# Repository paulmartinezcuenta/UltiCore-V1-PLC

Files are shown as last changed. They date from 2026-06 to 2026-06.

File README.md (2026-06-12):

# UltiCore V1 - ESP32-Based Industrial PLC 

UltiCore V1 is a high-reliability, industrial-grade Programmable Logic Controller (PLC) custom-designed around the **ESP32-WROOM-32D** architecture. Engineered for harsh electrical environments, this board features high-density optical isolation, dedicated buffered data buses, and a robust power management system.

---

##  Advanced Hardware Architecture & Engineering

### 1. Dual-Bus Data Architecture & Control Logic
* **Buffered Bus Isolation:** Implements octal three-state buffers (**74HC541TS**) to split control signals into dedicated **Power Data Buses** and **Analog Data Buses**. This topology isolates the MCU pins, maximizes fan-out capability, and prevents EMI crosstalk from high-current switching sections.
* **Industrial Output Stage (8-Channel Relay Matrix):** Features 8 independent mechanical relays driven by robust **2N3904** BJT switching circuits. Each channel is equipped with hardwired pull-down networks for deterministic power-up states and **RR1VWM6STFTR** flyback suppression diodes to clamp inductive back-EMF spikes.

### 2. High-Density Input Conditioning & Galvanic Isolation
* **Optically Isolated Digital Inputs:** 8 industrial-level input channels (`IN0`-`IN7`) isolated via high-density **ILD207T** dual optocouplers, establishing complete galvanic separation between the 24V field domain and the 3.3V logic domain.
* **Hardware Debouncing & Waveshaping:** Optocoupler outputs are routed through **74HC14** Hex Schmitt-Trigger inverters to suppress mechanical switch bounce and electrical noise, delivering sharp, clean square waves to the MCU.

### 3. Industrial Power Supply & Protection Framework
* **High-Efficiency Buck Topology:** Integrates an **LM2576HVS-3.3** switching regulator paired with a **100µH** power inductor and a **B330A** Schottky diode to efficiently step down standard industrial 24VDC rails directly to a stable 3.3V rail.
* **Smart Dual-Power Protection (Anti-USB & 24V Cross-Protection):** Utilizes an **LM358DR** operational amplifier comparator circuit coupled with a **PC817** optocoupler and an **FQD11P06** P-Channel MOSFET. This layout actively prevents reverse-current backfeeding and hardware damage when both the high-voltage field power and USB-C programming interface are active simultaneously.
* **Front-End Overcurrent & Polarity Defense:** Equipped with a standard 5x20mm cartridge fuse assembly and a high-current **5S14** blocking diode for reverse-polarity protection.

### 4. Modern Interface & ESD Compliance
* **USB-C Interface:** Modern USB-C implementation driven by a **CH340C** USB-to-UART bridge with an integrated dual-transistor auto-reset/boot-loader circuit.
* **Transient Voltage Suppression:** High-speed **LESD5D5.0CT1G** TVS diode arrays deployed on critical USB data lines (`D+`/`D-`) for localized ESD clamping.

---

## Repository Structure

```text
├── Hardware/        # KiCad schematic captures, multi-layer layout files, and structural BOM
├── Firmware/        # Modular C/C++ source code and RTOS industrial automation tasks
└── Docs/            # Hardware layout sheets, pinout mapping, and component datasheets

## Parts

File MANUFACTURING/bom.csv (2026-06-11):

Designator | Footprint | Quantity | Value | LCSC Part #
C1, C4, C6 | 0805 | 3 | 10uf_25v
C10 | C_Elec_10x10.2 | 1 | 470uf | C72518
C11 | C_Elec_6.3x7.7 | 1 | 47uf | C72523
C12 | C_Elec_8x10.2 | 1 | 220uf
C13, C14, C15, C16, C17, C18, C19, C20, C21, C22, C23, C24, C25, C26, C27, C28, C29, C30, C31, C32, C37, C38, C40, C41, C42, C43, C5, C9 | 0805 | 28 | 100nf
C2, C3 | 0805 | 2 | 0.1uf_50v
C34, C35, C36 | 0805 | 3 | 10uf
C7, C8 | 0805 | 2 | 0.1uf
CN1, CN3 | CONN-TH_2P-P5.08_DIBO_DB128V-5.08 | 2 | DB128V-5.08-2P-GN-S | C2915639
CN2 | CONN-TH_8P-P5.08_DB128V-5.08-8P-GN-S | 1 | DB128V-5.08-8P-GN-S | C5143711
D1, D11, D13, D4, D5, D6, D7, D9 | D_SOD-323 | 8 | 1N5819WS
D2, D23 | D_SMA | 2 | SS14
D22 | SOD-123_L2.7-W1.6-LS3.7-RD | 1 | 1N5819HW-7-F | C82544
D3 | D_SMA | 1 | B330A
DZ1, DZ2 | D_SOD-123 | 2 | MMSZ3V6
F1 | FUSE-TH_L22.6-W9.0 | 1 | 5x20 BLX-Atype Fuse holder XC-7 | C3131
J4 | PinHeader_1x04_P2.00mm_Vertical | 1 | Connect
K1, K2, K3, K4, K5, K6, K7, K8 | RELAY-TH_HF49FD-012-1H12G | 8 | HF49FD/012-1H12G | C340662
L2 | IND-SMD_L8.5-W8.0_PCC-M0854M | 1 | PSPMAA0805-101M-ANP | C2962892
LED1, LED2, LED3, LED4, LED5, LED6, LED7, LED8 | SolderWirePad_1x01_SMD_1x2mm | 8 | TestPoint_Flag
LED10, LED9 | LED0805-FD-GREEN | 2 | YLED0805G | C25170728
OC1 | DIP-4_W7.62mm_SMDSocket_SmallPads | 1 | PC817
OC2, OC3, OC4, OC5 | SO-8_3.9x6.2mm_P1.27mm | 4 | ILD207T
P1, P2, P5 | CONN-TH_3P-P5.00_WJ500V-5.08-3P | 3 | WJ500V-5.08-3P-14-00A | C72334
P3, P4 | CONN-TH_2P-P5.00_WJ500V-5.08-2P | 2 | WJ500V-5.08-2P-14-00A | C8465
Q1 | TO-252-2 | 1 | FQD11P06
Q10, Q11, Q13, Q14, Q15, Q5, Q6, Q7, Q8, Q9 | SOT-23-3_L2.9-W1.3-P1.90-LS2.4-TR | 10 | 2n3904S-RTK/PS_C18536 | C18536
R1, R10, R11, R2, R26, R27, R28, R29, R30, R31, R32, R33, R35, R36, R37, R38, R39, R40, R41, R42, R52, R53, R56, R59, R62, R65, R68, R7, R71, R8, R9 | 0805 | 31 | 10k
R12, R6 | 0805 | 2 | 2.2k
R13, R14, R16, R51, R54, R57, R60, R63, R66, R69, R72, R74, R75 | 0805 | 13 | 1k
R15, R17 | 0805 | 2 | 536
R18, R19, R20, R21, R22, R23, R24, R25 | 0805 | 8 | 20k
R5, R78 | 0805 | 2 | 5.11k
R76, R77 | 0805 | 2 | 0
SGM2212-3.1 | SOT-223 | 1 | ~
SW1 | SW-SMD_4P-L6.0-W6.0-P4.50-LS8.2 | 1 | BOOT | C7528752
SW3 | SW-SMD_4P-L6.0-W6.0-P4.50-LS8.2 | 1 | RESET | C7528752
TP1, TP2, TP4 | TestPoint_Pad_2.0x2.0mm | 3 | TestPoint_Small
TP3 | TestPoint_Pad_2.0x2.0mm | 1 | GND
TP6 | SolderWirePad_1x01_SMD_1.5x3mm | 1 | TestPoint_Flag
TP7 | TestPoint_Pad_2.0x2.0mm | 1 | GND_U10
U1, U2 | SOIC-14_L8.7-W3.9-P1.27-LS6.0-BL | 2 | 74HC14_C5356103 | C5356103
U10, U11 | TSSOP-20_L6.5-W4.4-P0.65-LS6.4-BL | 2 | 74HC541TS | C41433435
U13 | ESP32-WROOM-32D | 1 | ESP32-WROOM-32D
U14 | SOIC-16_3.9x9.9mm_P1.27mm | 1 | CH340C
U3 | TO-263-2 | 1 | L7812CD2T
U4, U6 | SOIC-8_L5.0-W4.0-P1.27-LS6.0-BL | 2 | LM358DR | C5423
U5, U8, U9 | SOT-23-3_L2.9-W1.3-P1.90-LS2.4 | 3 | SM05.TCT_C2687125 | C2687125
U7 | PG-TO-263-5_L10.2-W8.7-P1.70-LS14.4-BR | 1 | LM2576HVS-3.3 | C347436
USB2 | USB-C-SMD_HX-TYPE-C-16P-180-LT-H15.0 | 1 | HX-TYPE-C 16P 180 LT H15.0 | C49261573

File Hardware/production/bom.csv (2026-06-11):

Designator | Footprint | Quantity | Value | LCSC Part #
C1, C4, C6 | 0805 | 3 | 10uf_25v
C10 | C_Elec_4x5.4 | 1 | 470uf
C11 | C_Elec_4x5.4 | 1 | 47uf
C12 | C_Elec_4x5.4 | 1 | 220uf
C16, C17, C18, C19, C20, C21, C22, C23, C24, C25, C26, C27, C28, C29, C30, C31, C32, C33, C37, C38, C40, C41, C42, C5, C9 | 0805 | 25 | 100nf
C2, C3 | 0805 | 2 | 0.1uf_50v
C34, C35, C36 | 0805 | 3 | 10uf
C39 | 0805 | 1 | 10nf
C7, C8 | 0805 | 2 | 0.1uf
CN1, CN3 | CONN-TH_2P-P5.08_DIBO_DB128V-5.08 | 2 | DB128V-5.08-2P-GN-S | C2915639
CN2 | CONN-TH_8P-P5.08_DB128V-5.08-8P-GN-S | 1 | DB128V-5.08-8P-GN-S | C5143711
D10, D12, D14, D16, D18, D20, D6, D8 | PMDE_L2.2-W1.3-LS2.5-RD | 8 | RR1VWM6STFTR | C253524
D2, D23 | D_SMA | 2 | SS14
D22 | SOD-123_L2.7-W1.6-LS3.7-RD | 1 | 1N5819HW-7-F | C82544
D27, D28 | SOD-523_L1.2-W0.8-LS1.6-BI | 2 | LESD5D5.0CT1G | C383211
D29, D30, D31 | SOD-523_L1.2-W0.8-LS1.6-BI | 3 | LESD5D5.0CT1G | C5274290
D3 | D_SMA | 1 | B330A
F1 | 0805 | 1 | Fuse_Small 1A
K1, K2, K3, K4, K5, K6, K7, K8 | RELAY-TH_HF49FD-012-1H12G | 8 | HF49FD/012-1H12G | C340662
L2 | IND-SMD_L8.5-W8.0_PCC-M0854M | 1 | PSPMAA0805-101M-ANP | C2962892
OC1 | DIP-4_W7.62mm_SMDSocket_SmallPads | 1 | PC817
OC2, OC3, OC4, OC5 | SO-8_3.9x6.2mm_P1.27mm | 4 | ILD207T
P1, P2 | CONN-TH_3P-P5.00_WJ500V-5.08-3P | 2 | WJ500V-5.08-3P-14-00A | C72334
P3, P4 | CONN-TH_2P-P5.00_WJ500V-5.08-2P | 2 | WJ500V-5.08-2P-14-00A | C8465
Q1 | TO-252-2 | 1 | FQD11P06
Q10, Q11, Q13, Q14, Q15, Q16, Q2, Q4, Q5, Q6, Q7, Q8, Q9 | SOT-23-3_L2.9-W1.3-P1.90-LS2.4-TR | 13 | 2n3904S-RTK/PS_C18536 | C18536
R10, R11, R26, R27, R28, R29, R30, R31, R32, R33, R35, R36, R37, R38, R39, R40, R41, R42, R44, R45, R46, R47, R49, R52, R53, R56, R59, R62, R65, R68, R7, R71, R8, R9 | 0805 | 34 | 10k
R12, R5, R6, R78 | 0805 | 4 | 5.11k
R13, R34, R43, R48, R51, R54, R57, R60, R63, R66, R69, R72, R74, R75 | 0805 | 14 | 1k
R18, R19, R20, R21, R22, R23, R24, R25 | 0805 | 8 | 20k
R4 | 0805 | 1 | 1M
R50, R55, R58, R61, R64, R67, R70, R73 | 0805 | 8 | 4.7k
R76, R77 | 0805 | 2 | 0
SGM2212-3.1 | SOT-223 | 1 | ~
SW1 | SW-SMD_4P-L6.0-W6.0-P4.50-LS8.2 | 1 | BOOT | C7528752
SW3 | SW-SMD_4P-L6.0-W6.0-P4.50-LS8.2 | 1 | RESET | C7528752
TP1, TP2, TP4 | TestPoint_Pad_2.0x2.0mm | 3 | TestPoint_Small
TP3 | TestPoint_Pad_2.0x2.0mm | 1 | GND
U1, U2 | SOIC-14_L8.7-W3.9-P1.27-LS6.0-BL | 2 | 74HC14_C5356103 | C5356103
U10, U11 | TSSOP-20_L6.5-W4.4-P0.65-LS6.4-BL | 2 | 74HC541TS | C41433435
U12 | Toshiba_SOIC-4-6_4.4x3.6mm_P1.27mm | 1 | TLP127
U13 | ESP32-WROOM-32D | 1 | ESP32-WROOM-32D
U14 | SOIC-16_3.9x9.9mm_P1.27mm | 1 | CH340C
U3 | TO-263-2 | 1 | L7812CD2T
U4 | TO-263-5_TabPin3 | 1 | LM2576HVS-3.3
U5 | SO-8_3.9x4.9mm_P1.27mm | 1 | LM358M
USB1 | USB-C-SMD_TYPE-C-6PIN-2MD-073 | 1 | TYPE-C 16PIN 2MD(073) | C2765186

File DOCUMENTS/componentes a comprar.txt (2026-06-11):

Sp32-s3
https://www.lcsc.com/product-detail/C2913202.html?s_z=n_esp32

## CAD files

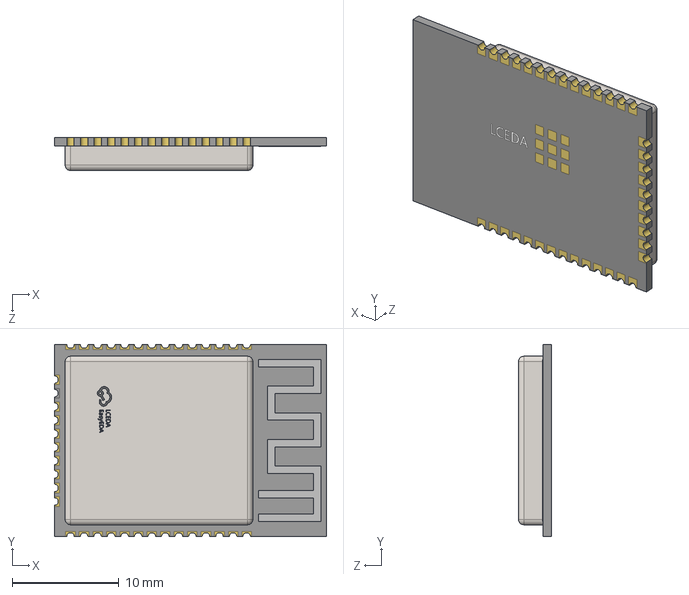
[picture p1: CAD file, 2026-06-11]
3D DESING/WIFI-SMD_L25.5-W18.0-H3.1-ESP32-WROOM-32E.step
25.5 x 18.0 x 3.10 mm

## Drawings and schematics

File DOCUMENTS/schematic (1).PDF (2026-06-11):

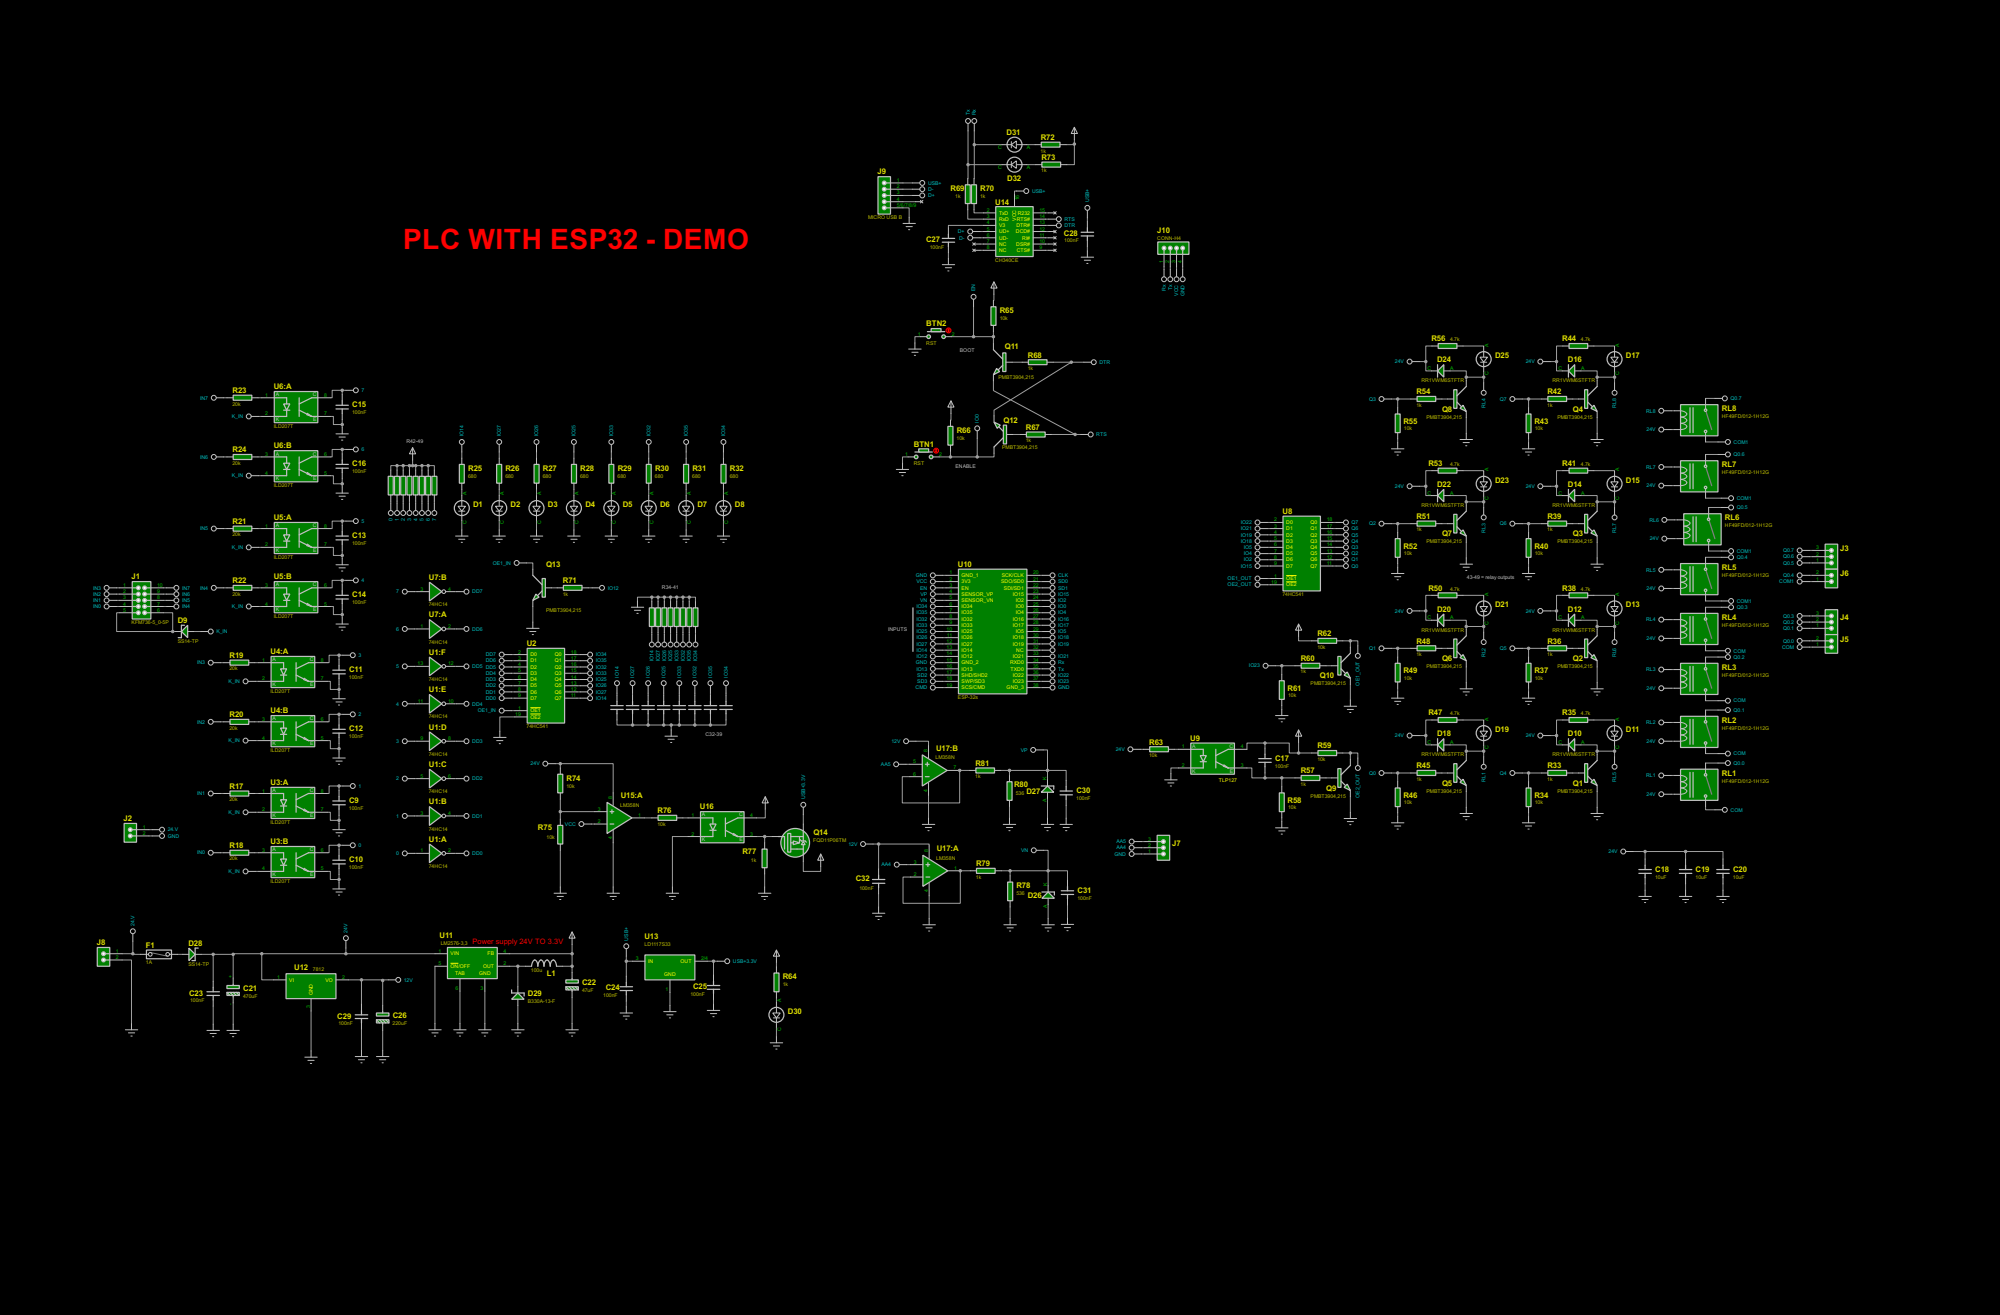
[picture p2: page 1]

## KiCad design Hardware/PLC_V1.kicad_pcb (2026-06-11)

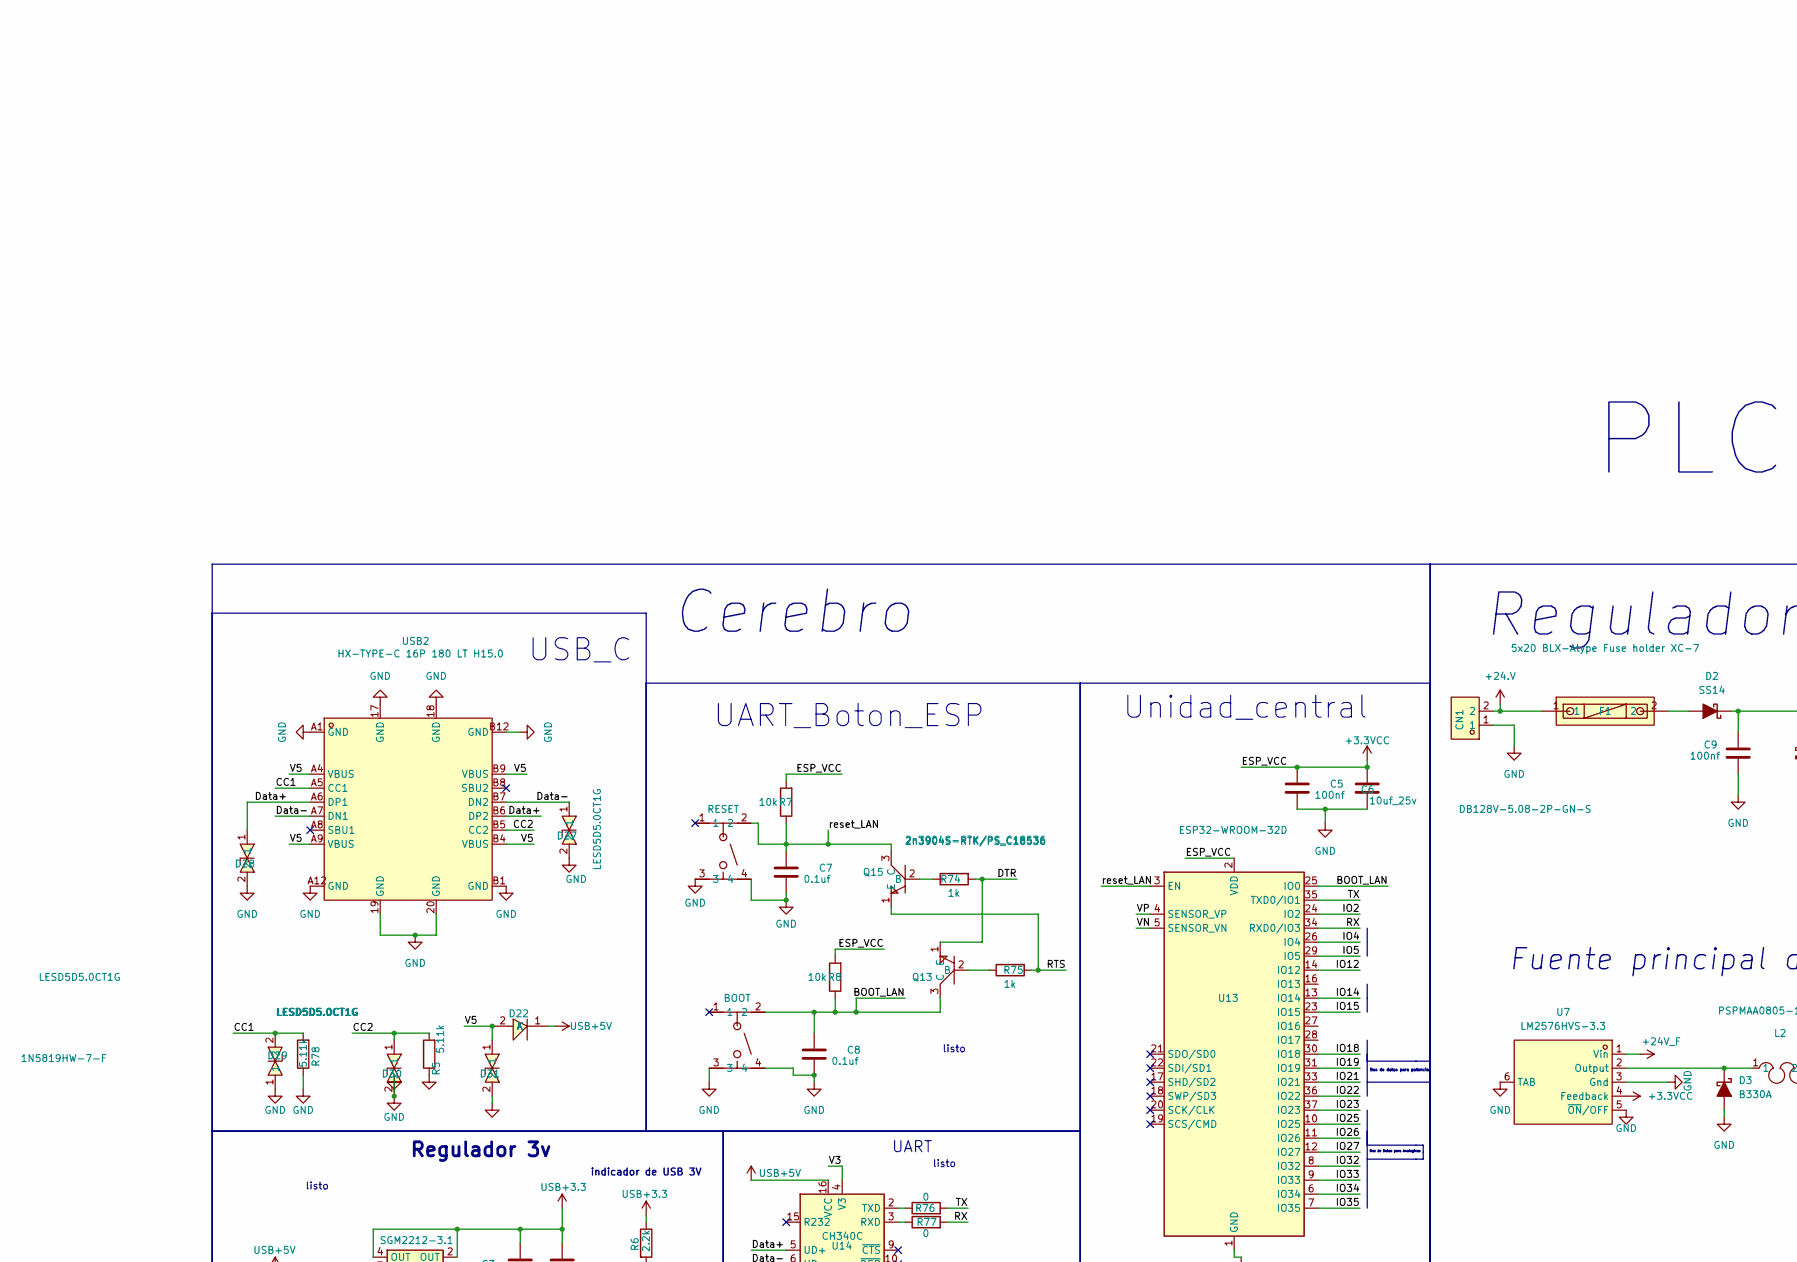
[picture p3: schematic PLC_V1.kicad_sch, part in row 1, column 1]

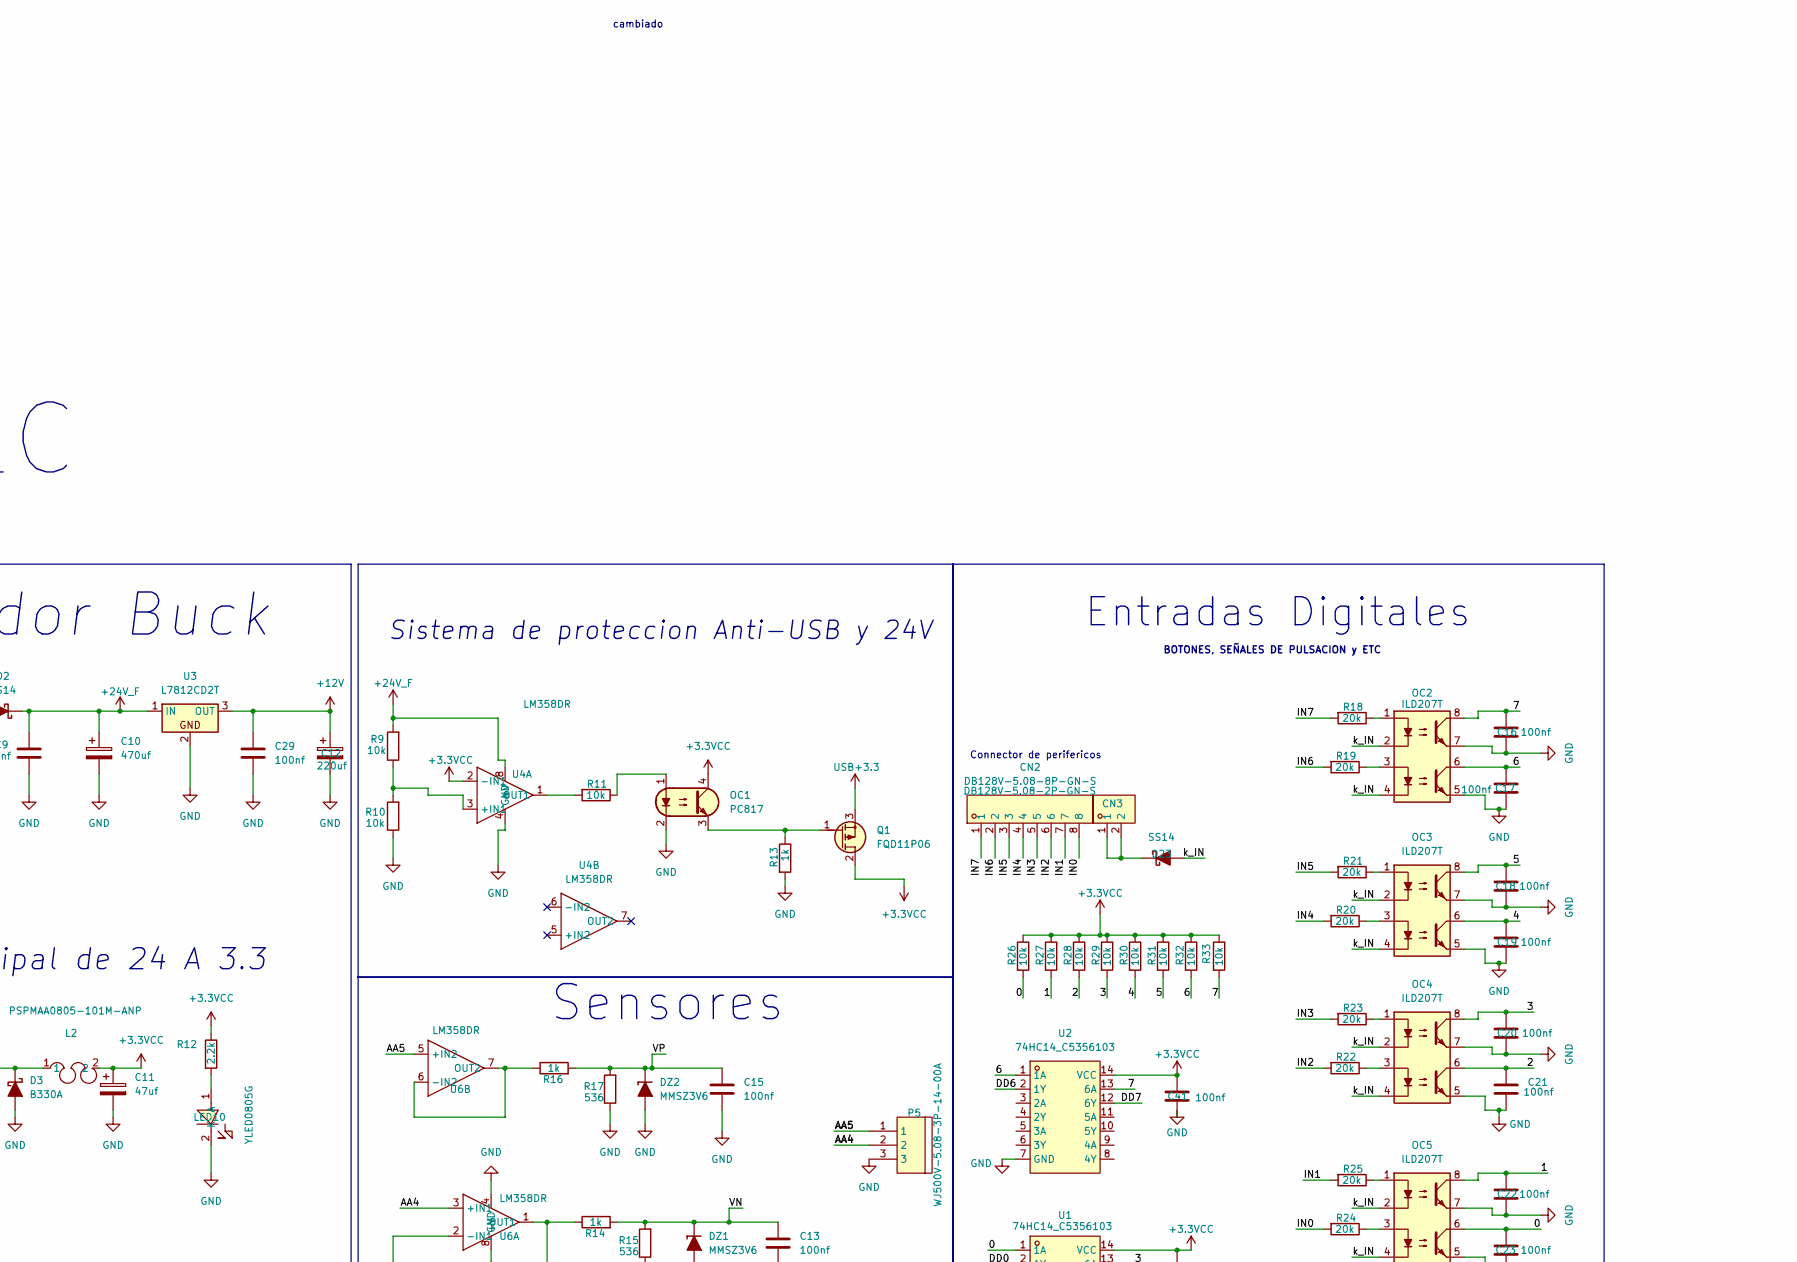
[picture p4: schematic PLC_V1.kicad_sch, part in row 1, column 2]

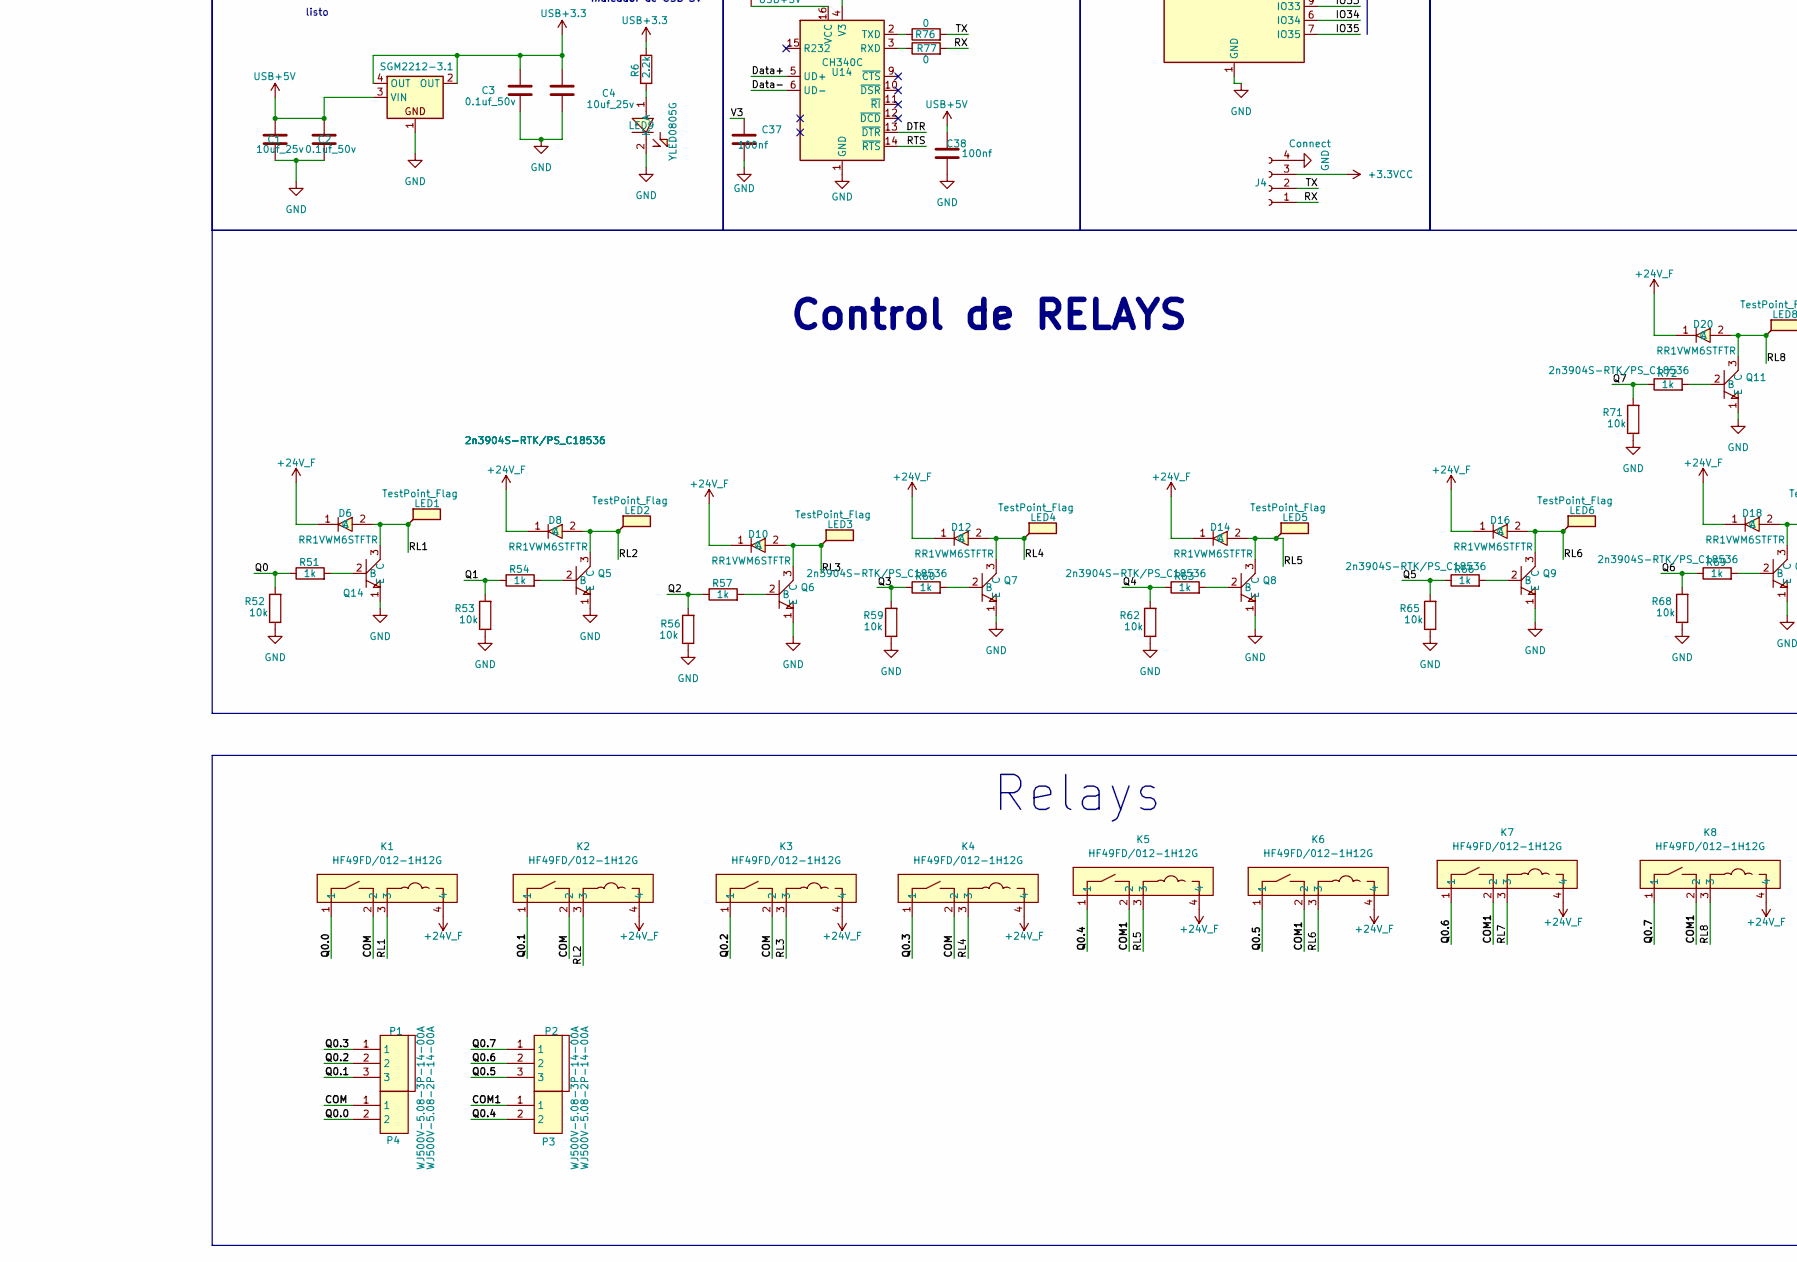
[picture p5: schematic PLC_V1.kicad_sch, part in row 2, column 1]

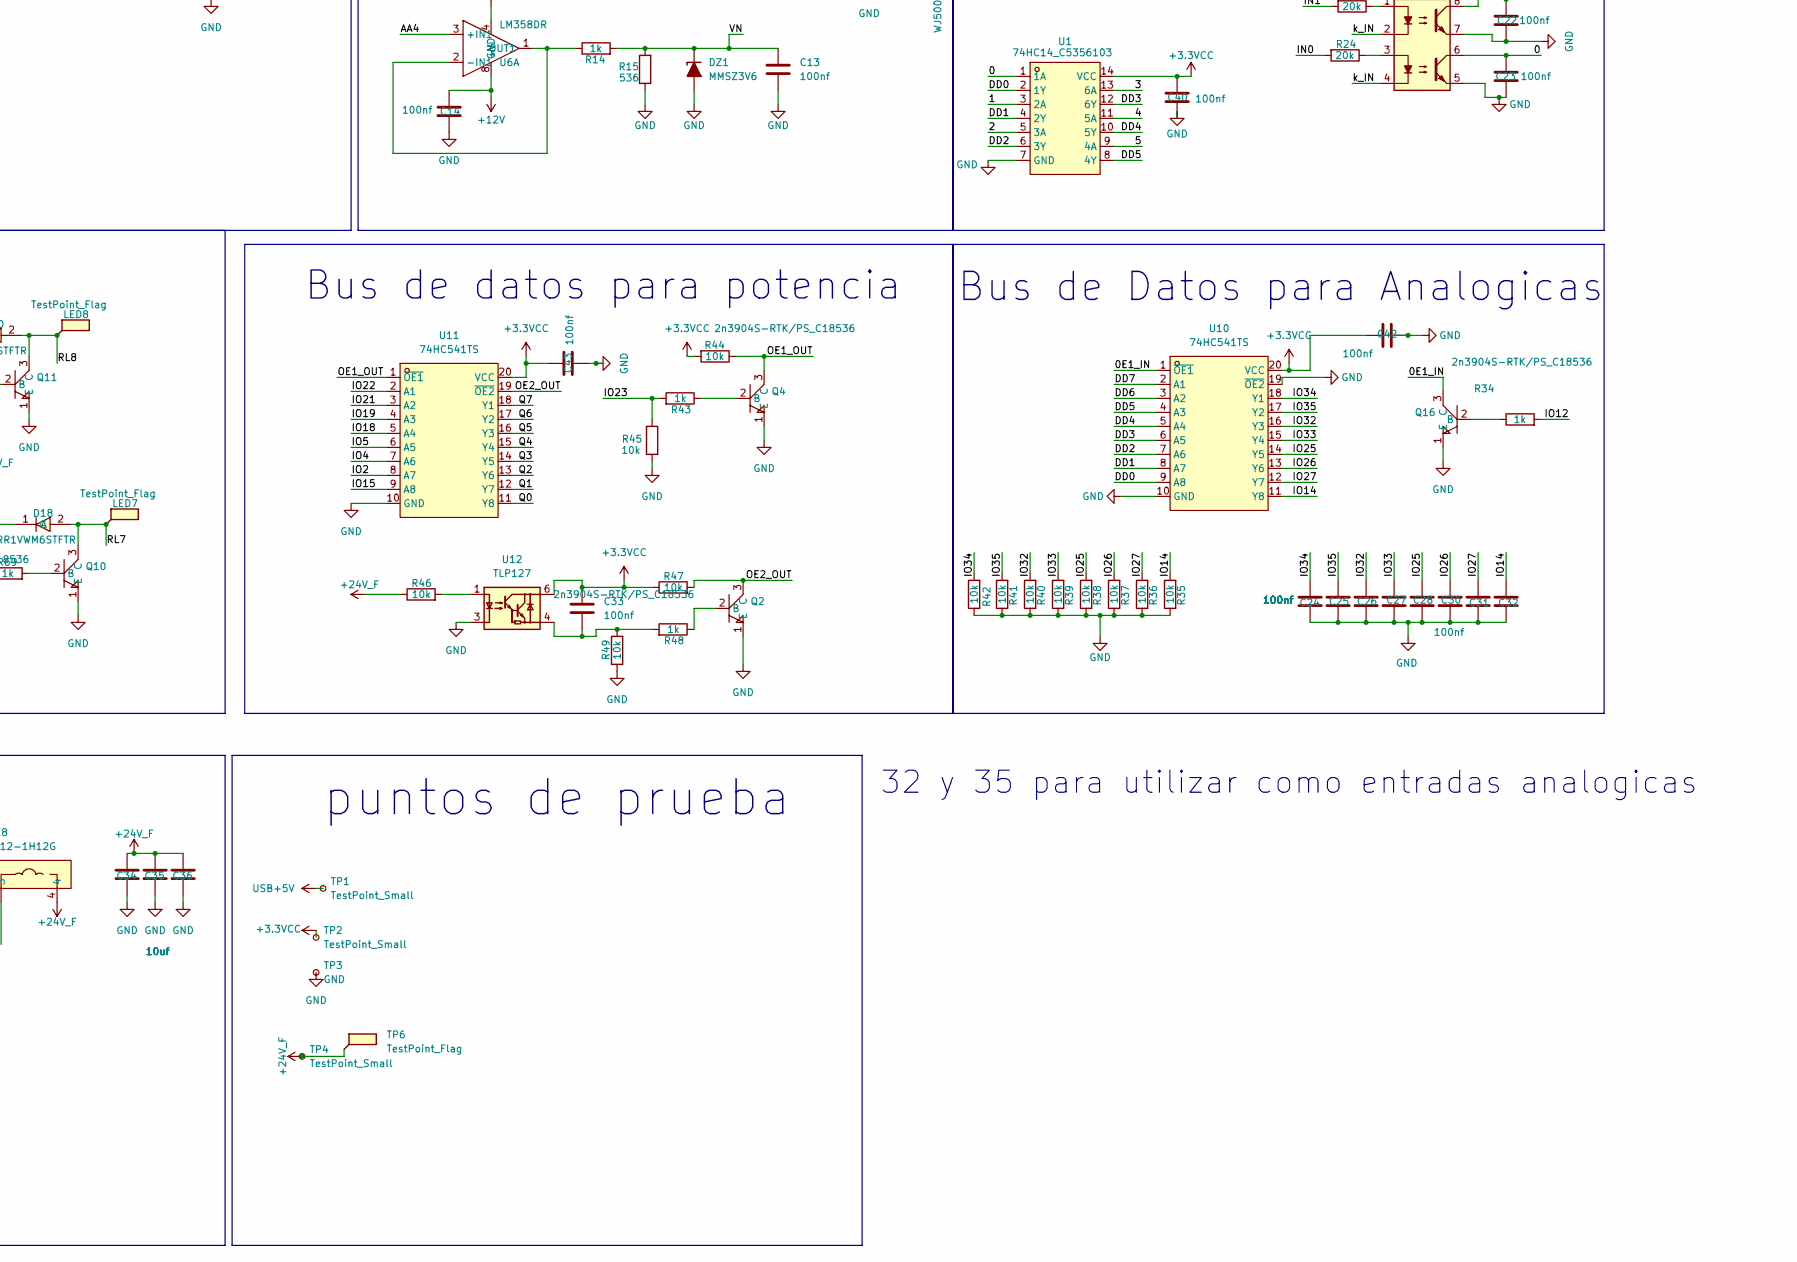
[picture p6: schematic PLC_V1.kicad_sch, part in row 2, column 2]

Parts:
C1, C4, C6: 10uf_25v; C_0805_2012Metric_Pad1.18x1.45mm_HandSolder
C2, C3: 0.1uf_50v; C_0805_2012Metric_Pad1.18x1.45mm_HandSolder
C5, C9, C13, C14, C15, C16, C17, C18, C19, C20, C21, C22, C23, C24, C25, C26, C27, C28, C29, C30, C31, C32, C33, C37, C38, C40, C41, C42, C43: 100nf; C_0805_2012Metric_Pad1.18x1.45mm_HandSolder
C7, C8: 0.1uf; C_0805_2012Metric_Pad1.18x1.45mm_HandSolder
C10: 470uf; C_Elec_10x10.2; LCSC C72518
C11: 47uf; C_Elec_6.3x7.7; LCSC C72523
C12: 220uf; C_Elec_8x10.2
C34, C35, C36: 10uf; C_0805_2012Metric_Pad1.18x1.45mm_HandSolder
CN1, CN3: DB128V-5.08-2P-GN-S; CONN-TH_2P-P5.08_DIBO_DB128V-5.08; LCSC Part C2915639
CN2: DB128V-5.08-8P-GN-S; CONN-TH_8P-P5.08_DB128V-5.08-8P-GN-S; LCSC Part C5143711
D2, D23: SS14; D_SMA
D3: B330A; D_SMA
D6, D8, D10, D12, D14, D16, D18, D20: RR1VWM6STFTR; PMDE_L2.2-W1.3-LS2.5-RD; LCSC Part C253524
D22: 1N5819HW-7-F; SOD-123_L2.7-W1.6-LS3.7-RD; LCSC Part C82544
D27, D28: LESD5D5.0CT1G; SOD-523_L1.2-W0.8-LS1.6-BI; LCSC Part C383211
D29, D30, D31: LESD5D5.0CT1G; SOD-523_L1.2-W0.8-LS1.6-BI; LCSC Part C5274290
DZ1, DZ2: MMSZ3V6; D_SOD-123
F1: 5x20 BLX-Atype Fuse holder XC-7; FUSE-TH_L22.6-W9.0; LCSC Part C3131
J4: Connect; PinHeader_1x04_P2.00mm_Vertical
K1, K2, K3, K4, K5, K6, K7, K8: HF49FD/012-1H12G; RELAY-TH_HF49FD-012-1H12G; LCSC Part C340662
L2: PSPMAA0805-101M-ANP; IND-SMD_L8.5-W8.0_PCC-M0854M; LCSC Part C2962892
LED1, LED2, LED3, LED4, LED5, LED6, LED7, LED8: TestPoint_Flag; SolderWirePad_1x01_SMD_1x2mm
LED9, LED10: YLED0805G; LED0805-FD-GREEN; LCSC Part C25170728
OC1: PC817; DIP-4_W7.62mm_SMDSocket_SmallPads
OC2, OC3, OC4, OC5: ILD207T; SO-8_3.9x6.2mm_P1.27mm
P1, P2, P5: WJ500V-5.08-3P-14-00A; CONN-TH_3P-P5.00_WJ500V-5.08-3P; LCSC Part C72334
P3, P4: WJ500V-5.08-2P-14-00A; CONN-TH_2P-P5.00_WJ500V-5.08-2P; LCSC Part C8465
Q1: FQD11P06; TO-252-2
Q2, Q4, Q5, Q6, Q7, Q8, Q9, Q10, Q11, Q13, Q14, Q15, Q16: 2n3904S-RTK/PS_C18536; SOT-23-3_L2.9-W1.3-P1.90-LS2.4-TR; LCSC Part C18536
R5, R78: 5.11k; R_0805_2012Metric_Pad1.20x1.40mm_HandSolder
R6, R12: 2.2k; R_0805_2012Metric_Pad1.20x1.40mm_HandSolder
R7, R8, R9, R10, R11, R26, R27, R28, R29, R30, R31, R32, R33, R35, R36, R37, R38, R39, R40, R41, R42, R44, R45, R46, R47, R49, R52, R53, R56, R59, R62, R65, R68, R71: 10k; R_0805_2012Metric_Pad1.20x1.40mm_HandSolder
R13, R14, R16, R34, R43, R48, R51, R54, R57, R60, R63, R66, R69, R72, R74, R75: 1k; R_0805_2012Metric_Pad1.20x1.40mm_HandSolder
R15, R17: 536; R_0805_2012Metric_Pad1.20x1.40mm_HandSolder
R18, R19, R20, R21, R22, R23, R24, R25: 20k; R_0805_2012Metric_Pad1.20x1.40mm_HandSolder
R76, R77: 0; R_0805_2012Metric_Pad1.20x1.40mm_HandSolder
SGM2212-3.1: SOT-223
SW1: BOOT; SW-SMD_4P-L6.0-W6.0-P4.50-LS8.2; LCSC Part C7528752
SW3: RESET; SW-SMD_4P-L6.0-W6.0-P4.50-LS8.2; LCSC Part C7528752
TP1, TP2, TP4: TestPoint_Small; TestPoint_Pad_2.0x2.0mm
TP3: GND; TestPoint_Pad_2.0x2.0mm
TP6: TestPoint_Flag; SolderWirePad_1x01_SMD_1.5x3mm
U1, U2: 74HC14_C5356103; SOIC-14_L8.7-W3.9-P1.27-LS6.0-BL; LCSC Part C5356103
U3: L7812CD2T; TO-263-2
U4, U6: LM358DR; SOIC-8_L5.0-W4.0-P1.27-LS6.0-BL; LCSC Part C5423
U7: LM2576HVS-3.3; PG-TO-263-5_L10.2-W8.7-P1.70-LS14.4-BR; LCSC Part C347436
U10, U11: 74HC541TS; TSSOP-20_L6.5-W4.4-P0.65-LS6.4-BL; LCSC Part C41433435
U12: TLP127; Toshiba_SOIC-4-6_4.4x3.6mm_P1.27mm
U13: ESP32-WROOM-32D
U14: CH340C; SOIC-16_3.9x9.9mm_P1.27mm
USB2: HX-TYPE-C 16P 180 LT H15.0; USB-C-SMD_HX-TYPE-C-16P-180-LT-H15.0; LCSC Part C49261573

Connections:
+3.3VCC: C5.1, C6.1, C11.1, C33.1, C40.2, C41.2, C42.1, C43.2, J4.3, L2.2, OC1.4, Q1.2 (D), R7.2, R8.2, R12.1, R26.1, R27.1, R28.1, R29.1, R30.1, R31.1, R32.1, R33.1, R44.2, R47.1, TP2.1, U1.14 (VCC), U2.14 (VCC), U4.2 (-IN1), U7.4 (Feedback), U10.20 (VCC), U11.20 (VCC), U12.6, U13.2 (VDD)
+12V: C12.1, C14.1, C29.1, U3.3 (OUT), U6.8 (+V)
+24.V: CN1.2, F1.1
+24V_F: C9.1, C10.1, C34.1, C35.1, C36.1, D2.1 (K), D6.1 (C), D8.1 (C), D10.1 (C), D12.1 (C), D14.1 (C), D16.1 (C), D18.1 (C), D20.1 (C), K1.4, K2.4, K3.4, K4.4, K5.4, K6.4, K7.4, K8.4, R9.2, R46.1, TP4.1, TP6.1, U3.1 (IN), U4.8 (+V), U7.1 (Vin); also elsewhere on the board
/0: C23.1, OC5.6, R26.2, U1.1 (1A)
/0E1_IN: Q16.3 (C), U10.1 (~OE1)
/1: C22.1, OC5.8, R27.2, U1.3 (2A)
/2: C21.1, OC4.6, R28.2, U1.5 (3A)
/3: C20.1, OC4.8, R29.2, U1.13 (6A)
/4: C19.1, OC3.6, R30.2, U1.11 (5A)
/5: C18.1, OC3.8, R31.2, U1.9 (4A)
/6: C17.1, OC2.6, R32.2, U2.1 (1A)
/7: C16.1, OC2.8, R33.2, U2.13 (6A)
/AA4: P5.2, U6.3 (+IN1)
/AA5: P5.1, U6.5 (+IN2)
/BOOT_LAN: C8.1, Q13.3 (C), R8.1, SW1.2, U13.25 (IO0)
/CC1: D29.2, R78.2, USB2.A5 (CC1)
/CC2: D30.1, R5.2, USB2.B5 (CC2)
/COM: K1.2, K2.2, K3.2, K4.2, P4.1
/COM1: K5.2, K6.2, K7.2, K8.2, P3.1
/DD0: U1.2 (1Y), U10.9 (A8)
/DD1: U1.4 (2Y), U10.8 (A7)
/DD2: U1.6 (3Y), U10.7 (A6)
/DD3: U1.12 (6Y), U10.6 (A5)
/DD4: U1.10 (5Y), U10.5 (A4)
/DD5: U1.8 (4Y), U10.4 (A3)
/DD6: U2.2 (1Y), U10.3 (A2)
/DD7: U2.12 (6Y), U10.2 (A1)
/DTR: Q13.1 (E), R74.2, U14.13 (~DTR)
/Data+: D28.1, U14.5 (UD+), USB2.A6 (DP1), USB2.B6 (DP2)
/Data-: D27.1, U14.6 (UD-), USB2.A7 (DN1), USB2.B7 (DN2)
/IN0: CN2.8, R24.2
/IN1: CN2.7, R25.2
/IN2: CN2.6, R22.2
/IN3: CN2.5, R23.2
/IN4: CN2.4, R20.2
/IN5: CN2.3, R21.2
/IN6: CN2.2, R19.2
/IN7: CN2.1, R18.2
/IO2: U11.8 (A7), U13.24 (IO2)
/IO4: U11.7 (A6), U13.26 (IO4)
/IO5: U11.6 (A5), U13.29 (IO5)
/IO12: R34.2, U13.14 (IO12)
/IO14: C32.1, R35.2, U10.11 (Y8), U13.13 (IO14)
/IO15: U11.9 (A8), U13.23 (IO15)
/IO18: U11.5 (A4), U13.30 (IO18)
/IO19: U11.4 (A3), U13.31 (IO19)
/IO21: U11.3 (A2), U13.33 (IO21)
/IO22: U11.2 (A1), U13.36 (IO22)
/IO23: R43.2, R45.1, U13.37 (IO23)
/IO25: C28.1, R38.2, U10.14 (Y5), U13.10 (IO25)
/IO26: C30.1, R37.2, U10.13 (Y6), U13.11 (IO26)
/IO27: C31.1, R36.2, U10.12 (Y7), U13.12 (IO27)
/IO32: C26.1, R40.2, U10.16 (Y3), U13.8 (IO32)
/IO33: C27.1, R39.2, U10.15 (Y4), U13.9 (IO33)
/IO34: C24.1, R42.2, U10.18 (Y1), U13.6 (IO34)
/IO35: C25.1, R41.2, U10.17 (Y2), U13.7 (IO35)
/OE1_OUT: Q4.3 (C), R44.1, U11.1 (~OE1)
/OE2_OUT: Q2.3 (C), R47.2, U11.19 (~OE2)
/Q0: R51.1, R52.2, U11.11 (Y8)
/Q0.0: K1.1, P4.2
/Q0.1: K2.1, P1.3
/Q0.2: K3.1, P1.2
/Q0.3: K4.1, P1.1
/Q0.4: K5.1, P3.2
/Q0.5: K6.1, P2.3
/Q0.6: K7.1, P2.2
/Q0.7: K8.1, P2.1
/Q1: R53.2, R54.1, U11.12 (Y7)
/Q2: R56.2, R57.1, U11.13 (Y6)
/Q3: R59.2, R60.1, U11.14 (Y5)
/Q4: R62.2, R63.1, U11.15 (Y4)
/Q5: R65.2, R66.1, U11.16 (Y3)
/Q6: R68.2, R69.1, U11.17 (Y2)
/Q7: R71.2, R72.1, U11.18 (Y1)
/RL1: D6.2 (A), K1.3, LED1.1, Q14.3 (C)
/RL2: D8.2 (A), K2.3, LED2.1, Q5.3 (C)
/RL3: D10.2 (A), K3.3, LED3.1, Q6.3 (C)
/RL4: D12.2 (A), K4.3, LED4.1, Q7.3 (C)
/RL5: D14.2 (A), K5.3, LED5.1, Q8.3 (C)
/RL6: D16.2 (A), K6.3, LED6.1, Q9.3 (C)
/RL7: D18.2 (A), K7.3, LED7.1, Q10.3 (C)
/RL8: D20.2 (A), K8.3, LED8.1, Q11.3 (C)
/RTS: Q15.1 (E), R75.2, U14.14 (~RTS)
/RX: J4.1, R77.2, U13.34 (RXD0/IO3)
/TX: J4.2, R76.2, U13.35 (TXD0/IO1)
/V3: C37.1, U14.4 (V3)
/V5: D22.2 (A), D31.1, USB2.A4 (VBUS), USB2.A9 (VBUS), USB2.B4 (VBUS), USB2.B9 (VBUS)
/VN: C13.1, DZ1.1 (K), R14.2, R15.2, U13.5 (SENSOR_VN)
/VP: C15.1, DZ2.1 (K), R16.2, R17.2, U13.4 (SENSOR_VP)
/k_IN: D23.2 (A), OC2.2, OC2.4, OC3.2, OC3.4, OC4.2, OC4.4, OC5.2, OC5.4
/reset_LAN: C7.1, Q15.3 (C), R7.1, SW3.2, U13.3 (EN)
GND: C1.2, C2.2, C3.2, C4.2, C5.2, C6.2, C7.2, C8.2, C9.2, C10.2, C11.2, C12.2, C13.2, C14.2, C15.2, C16.2, C17.2, C18.2, C19.2, C20.2, C21.2, C22.2, C23.2, C24.2, C25.2, C26.2, C27.2, C28.2, C29.2, C30.2, C31.2, C32.2, C34.2, C35.2, C36.2, C37.2, C38.2, C40.1, C41.1, C42.2, C43.1, CN1.1, D3.2 (A), D27.2, D28.2, D29.1, D30.2, D31.2, DZ1.2 (A), DZ2.2 (A), J4.4, LED9.2 (K), LED10.2 (K), OC1.2, OC2.5, OC2.7, OC3.5, OC3.7, OC4.5, OC4.7, OC5.5, OC5.7, P5.3, Q2.1 (E), Q4.1 (E), Q5.1 (E), Q6.1 (E), Q7.1 (E), Q8.1 (E), Q9.1 (E), Q10.1 (E), Q11.1 (E), Q14.1 (E), Q16.1 (E), R5.1, R10.1, R13.2, R15.1, R17.1, R35.1, R36.1, R37.1, R38.1, R39.1, R40.1, R41.1, R42.1, R45.2, R49.1, R52.1, R53.1, R56.1, R59.1, R62.1, R65.1, R68.1, R71.1, R78.1, SGM2212-3.1.1, SW1.3, SW1.4, SW3.3, SW3.4, TP3.1, U1.7 (GND), U2.7 (GND), U3.2, U4.4 (GND), U6.4 (GND), U7.3 (Gnd), U7.5 (~ON/OFF), U7.6 (TAB), U10.10 (GND), U10.19 (~OE2), U11.10 (GND), U12.3, U13.1 (GND), U13.15 (GND), U13.38 (GND), U13.39 (GND), U14.1 (GND), USB2.17 (GND), USB2.18 (GND), USB2.19 (GND), USB2.20 (GND), USB2.A1 (GND), USB2.A12 (GND), USB2.B1 (GND), USB2.B12 (GND)
unnamed: C33.2, R48.2, R49.2, U12.4
unnamed: D2.2 (A), F1.2
unnamed: D3.1 (K), L2.1, U7.2 (Output)
unnamed: CN3.1, CN3.2, D23.1 (K)
unnamed: LED9.1 (A), R6.2
unnamed: LED10.1 (A), R12.2
unnamed: OC1.1, R11.1
unnamed: OC2.1, R18.1
unnamed: OC2.3, R19.1
unnamed: OC3.1, R21.1
unnamed: OC3.3, R20.1
unnamed: OC4.1, R23.1
unnamed: OC4.3, R22.1
unnamed: OC5.1, R25.1
unnamed: OC5.3, R24.1
unnamed: OC1.3, Q1.1 (G), R13.1
unnamed: Q2.2 (B), R48.1
unnamed: Q4.2 (B), R43.1
unnamed: Q5.2 (B), R54.2
unnamed: Q6.2 (B), R57.2
unnamed: Q7.2 (B), R60.2
unnamed: Q8.2 (B), R63.2
unnamed: Q9.2 (B), R66.2
unnamed: Q10.2 (B), R69.2
unnamed: Q11.2 (B), R72.2
unnamed: Q13.2 (B), R75.1
unnamed: Q14.2 (B), R51.2
unnamed: Q15.2 (B), R74.1
unnamed: Q16.2 (B), R34.1
unnamed: R46.2, U12.1
unnamed: R9.1, R10.2, U4.3 (+IN1)
unnamed: R11.2, U4.1 (OUT1)
unnamed: R14.1, U6.1 (OUT1), U6.2 (-IN1)
unnamed: R16.1, U6.6 (-IN2), U6.7 (OUT2)
unnamed: R77.1, U14.3 (RXD)
unnamed: R76.1, U14.2 (TXD)
USB+3.3: C3.1, C4.1, Q1.3 (S), R6.1, SGM2212-3.1.2 (OUT), SGM2212-3.1.4 (OUT)
USB+5V: C1.1, C2.1, C38.1, D22.1 (K), SGM2212-3.1.3 (VIN), TP1.1, U14.16 (VCC)

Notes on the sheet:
Regulador Buck
PLC
Relays
USB_C
BOTONES, SEÑALES DE PULSACION y ETC
Sistema de proteccion Anti-USB y 24V
listo
UART_Boton_ESP
cambiado
UART
Bus de datos para potencia
Fuente principal de 24 A 3.3
puntos de prueba
Entradas Digitales
Bus de Datos para Analogicas
Cerebro
Control de RELAYS
32 y 35 para utilizar como entradas analogicas
indicador de USB 3V
Connector de perifericos
Unidad_central
Regulador 3v
Sensores

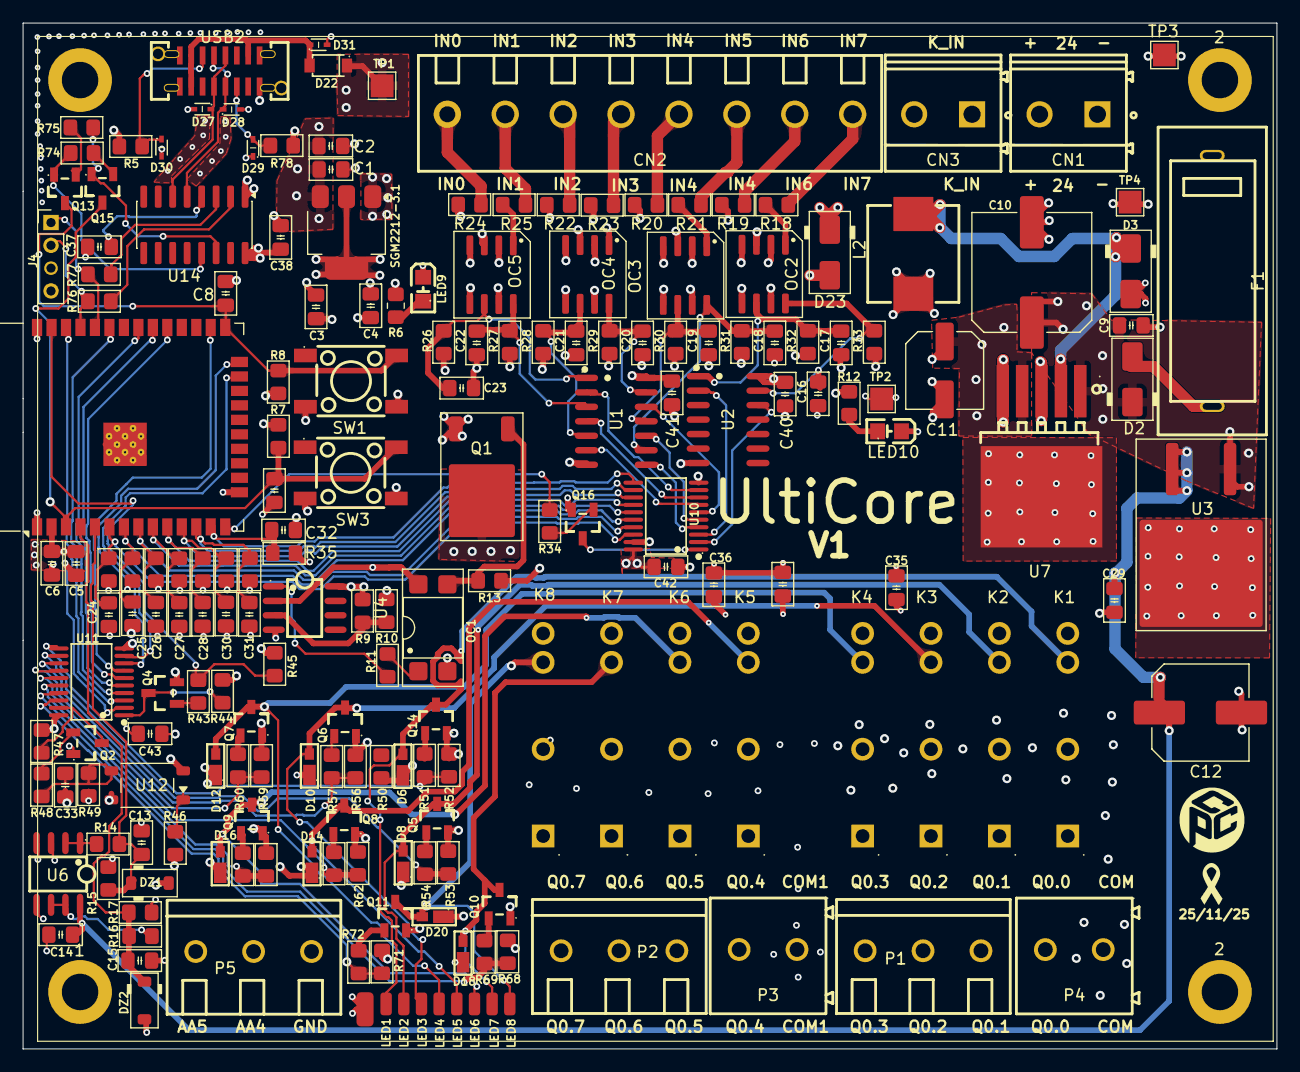
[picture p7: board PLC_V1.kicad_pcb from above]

Board: 4 copper layers, 110.0 x 90.0 mm, 202 parts (0 on the bottom side), 131 nets.

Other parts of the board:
1, 2, 2#2, 2#3: MountingHole_3.2mm_M3_DIN965_Pad
R50: 4.7k; R_0805_2012Metric_Pad1.20x1.40mm_HandSolder
THECPCENTER: LOGO; IMG1
_: LOGO; LUTO LOGO BIEN

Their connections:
+24V_F: R50.1; also elsewhere on the board

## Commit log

2026-05-27 Add core KiCad schematics and hardware layout files for UltiCore V1
    [PLC_V1.kicad_pcb, PLC_V1.kicad_sch]
2026-06-11 Organización
    [PLC_V1.kicad_pcb, PLC_V1.kicad_sch, WIFI-SMD_L25.5-W18.0-H3.1-ESP32-WROOM-32E.step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]
2026-06-11 Actualización de archivos
    [PLC_V1.kicad_pcb, PLC_V1.kicad_sch, WIFI-SMD_L25.5-W18.0-H3.1-ESP32-WROOM-32E.step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]
